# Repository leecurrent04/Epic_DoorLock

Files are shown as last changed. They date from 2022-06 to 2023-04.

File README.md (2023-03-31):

# EPIC Door Lock Project

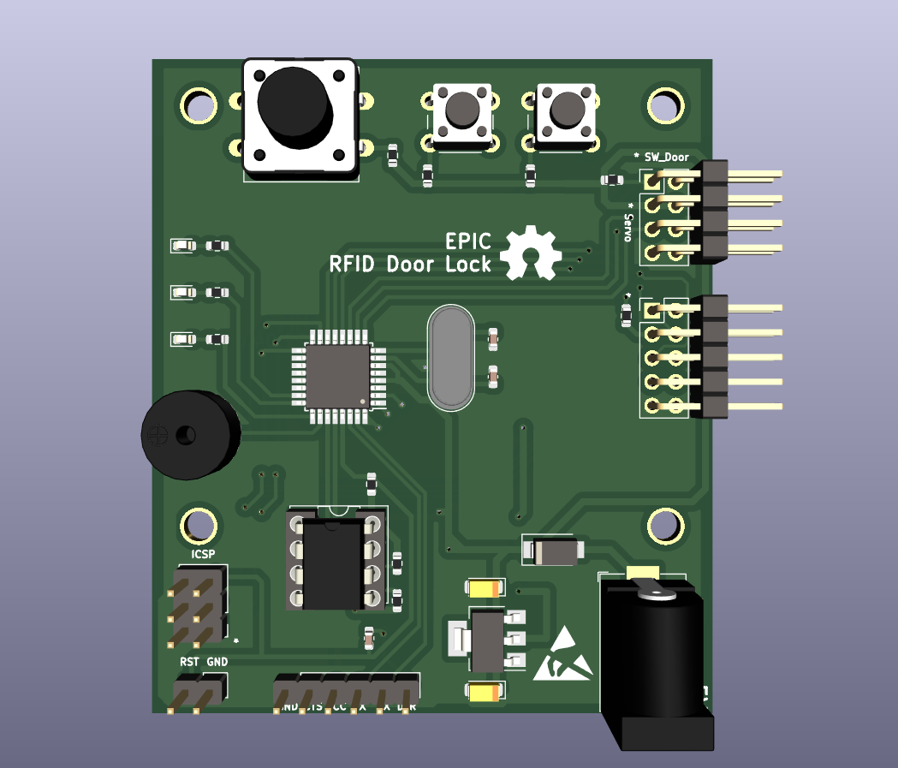
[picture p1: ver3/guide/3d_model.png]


## 1. 프로젝트 소개

연초고등학교 EPIC 동아리(2021~2022) 에서 교내 학생들의 자발적인 탐구 활동을 장려하기 위해 진행한 프로젝트 입니다.<br>
하드웨어 설계는 [KiCAD](https://www.kicad.org/) 를 사용하였고, 소프트웨어는 avr-gcc 컴파일러를 이용한 avr C 언어로 작성되었습니다.

<br>

## 2. 컴파일

Makefile을 이용하여 컴파일하는 경우, Makefile과 같은 위치에 `out` 폴더를 생성해야 합니다.

| 필요한 패키지 | 설명 |
| :---: | :--- |
| avr-gcc | 컴파일러 |
| avr-libc | 라이브러리 |
| avr-size | 메모리 사용량 확인 |
| avrdude | 업로더 |

<br>

### 1. in Linux

1. Set up (Debian)
    <br>
    패키지 설치는 Debian 기준으로 설명하고 있습니다. 자신의 환경에 맞추어 사용하시길 바랍니다.
    <br>

    ```console
    apt update && apt upgrade
    apt install avr-gcc avr-libc avr-size avrdude
    ```
    <br>

2. Download source code
    <br>
    ```console
    git clone https://github.com/leecurrent04/Epic_DoorLock
    cd ./Epic_DoorLock/ver3/code/avr/
    ```
    <br>

3. Set admin card
    <br>
    [main.c](https://github.com/leecurrent04/Epic_DoorLock/blob/main/ver3/code/avr/main.c) 파일의 16, 17줄을 편집하여 관리자 카드를 등록합니다.<br>
    RFID 카드의 4byte UID 코드를 1byte씩 기입합니다. 카드의 UID 코드는 [[NFC Tools - Google Play]](https://play.google.com/store/apps/details?id=com.wakdev.wdnfc&hl=en) 프로그램을 통하여 알 수 있습니다. (프로그램내 시리얼 번호 확인)<br>
    반드시 등록한 관리자 카드의 갯수에 맞게 `cardAdmin_Num` 값을 변경해주어야 합니다.
    <br>
    ```c
    #define cardAdmin_Num 2
    uint8_t cardAdmin_UID[cardAdmin_Num][4] = {
            {0x12, 0x34, 0x56, 0x78},
            {0x0A, 0x0B, 0x0C, 0x0D}
    };
    ```
    <br>

4. Complile
    <br>
    변경 사항을 저장한 후 아래 명령어를 이용하여 코드를 컴파일 합니다.
    <br>
    ```console
    mkdir out
    make all
    ```
    <br>또는 다음과 같은 명령어를 사용할 수 있습니다.<br>

    ```console
	avr-gcc -Wall -mmcu=atmega168p -Os main.c ./lib/* -o ./out/output.o
	avr-objcopy -j .text -j .data -O ihex ./out/output.o ./out/main.hex
    ```
    <br>

5. Upload
    <br>
    [Makefile](https://github.com/leecurrent04/Epic_DoorLock/blob/main/ver3/code/avr/Makefile) 의 2, 4, 5번째 줄을 환경에 맞게 편집합니다.<br>

    ```makefile
    PORT=/dev/ttyUSB0       # SET YOUR PORT
    OBJ_FILES=./lib/*
    BaudRate=115200         # SET BuadRate
    PROGRAMMER=arduino      # SET Programmer
    ```

    <br>아래의 명령어를 터미널에 입력하여 업로드 합니다.<br>

    ```console
    make flash
    ```

    <br>USBtinyISP를 사용하는 경우(권장), 다음의 명령어를 터미널에 입력하면 됩니다.<br>

    ```console
	avrdude -v -p m168p -c usbtiny -U flash:w:./out/main.hex:i
    ```

    <br><br>

### 2. Windows & Mac

[Microchip AVR GCC Compiler](https://www.microchip.com/en-us/tools-resources/develop/microchip-studio/gcc-compilers) 를 사용하여 Linux와 같은 과정을 따르거나, ATMEL Studio를 사용하십시오. <br>
자세한 과정은 『아트멜 스튜디오와 아두이노로 배우는 ATmega328 프로그래밍(허경용)』 도서를 참고하십시오.<br>
(이 프로젝트는 ATmega168p을 사용하였으므로, 업로드 과정에서 유의)
<br><br>

## 4. 참고 라이브러리

RFID 관련 AVR 라이브러리 : https://github.com/asif-mahmud/MIFARE-RFID-with-AVR

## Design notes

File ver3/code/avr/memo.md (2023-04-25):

-----

# library

https://github.com/asif-mahmud/MIFARE-RFID-with-AVR

-----

# Var: doorState

doorState 변수는 문 열림 동작에 관여하는 변수이다. <br> 
다음과 같은 변수를 사용하지 않는다면, 도어락이 정상적으로 작동하지 않을 우려가 있다.<br><br>

### 동작 과정) doorState = 0b00;

|  No | Situation | 0b_0  | 0b0_  | PIND6 |
| :---: | :--- | :---: | :---: | :---: |
| 1 | Normal | 0 | 0 | 0 |
| 2 | BTN Pressed | 1 | 1 | 0 |
| 3 | When Door opened  | 1 | 1 | 1 |
| 4 | After Door opened | 1 | 0 | 1 |
| 5 | Door closed | 1 | 0 | 0 |
| 6 | Normal | 0 | 0 | 0 |

<br>PIND6 는 문열림 감지 스위치이다. 풀 업(PULL UP) 저항으로 동작하지만, 이해를 위해 풀 다운(PULL DOWN)으로 상황으로 작성하였다. 실제 코드에서는 풀업 기준으로 작성되어 있다.<br><br>

# Var: btnPressed

btnPressed 변수는 도어락 버튼 동작에 관여하는 변수이다. <br>
각 버튼의 PIN을 사용하지 않고 btnPressed 변수를 사용함으로써 채터링 현상을 방지할 수 있다.<br>

BTN_D2 : 0b100  : 열기 버튼 <br>
BTN_D3 : 0b010  : 등록 버튼 <br>
BTN_D4 : 0b001  : 삭제 버튼 <br>
<br><br>

### 동작 과정)
|  No | Situation |  var  | BTN_Dn |
| :---: | :--- | :---: | :----: |
| 1 | Normal | 0 | 0 |
| 2 | When BTN Pressed  | 0 | 1 |
| 3 | After BTN Pressed | 1 | 1 |
| 4 | BTN Unpressed | 1 | 0 |
| 5 | Execute Function  | 1 | 0 |
| 6 | Normal | 0 | 0 |

<br>

-----

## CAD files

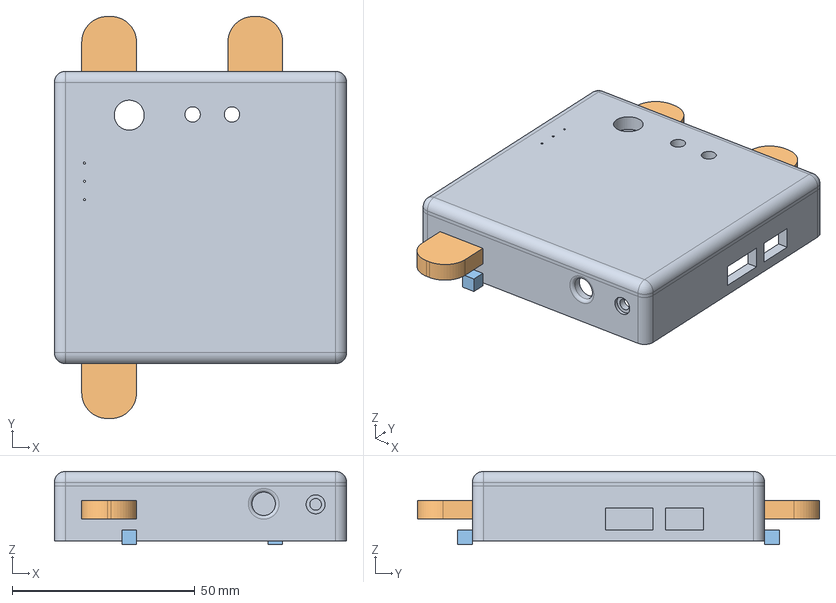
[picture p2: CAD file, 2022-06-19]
ver3/3D/RFID_Case-cover.step
80.0 x 110.0 x 20.0 mm
top
guide_cover
guide_cover001
guide_cover002
lock
lock001
lock002

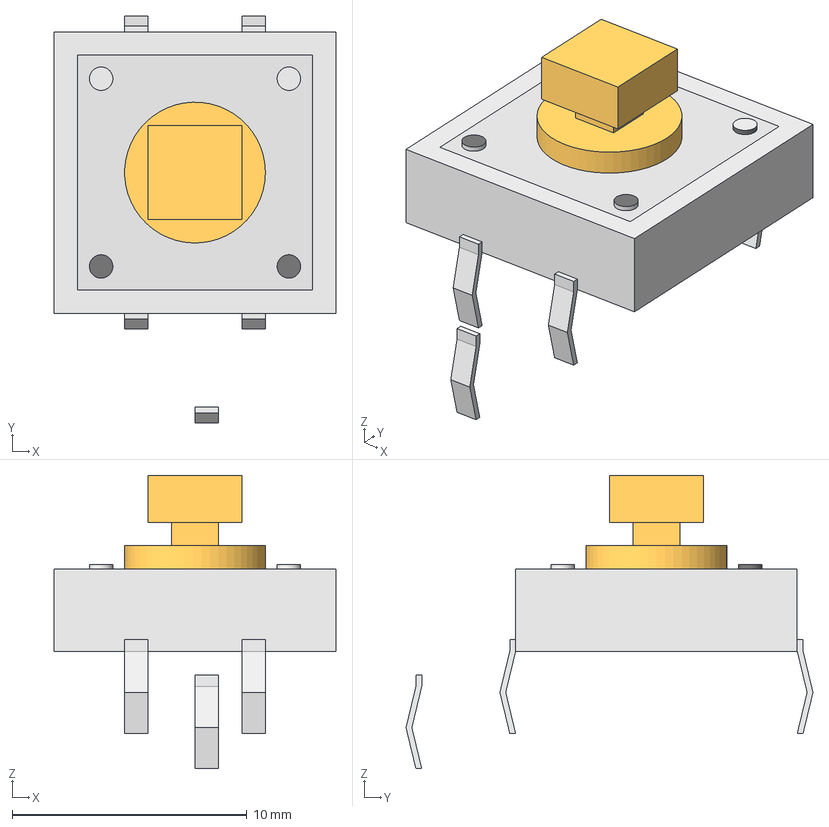
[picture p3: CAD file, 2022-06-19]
ver3/pcb/lib_o/NW3-TS-G008.step
12.0 x 17.3 x 12.5 mm
inner_Body x 2
knob x 2
leg x 2
Sketch
Sketch001
Local_CS
CopyChamfer
Sketch002
Sketch003
Local_CS001
Local_CS002
CopyPad001
Sketch004
BaseFeature
Local_CS003
CopyPocket001
Sketch005
Sketch006
Sketch007
Sketch008
Sketch009
Pad005 (Mirror #1)
leg (Mirror #2)
Pad005 (Mirror #3)

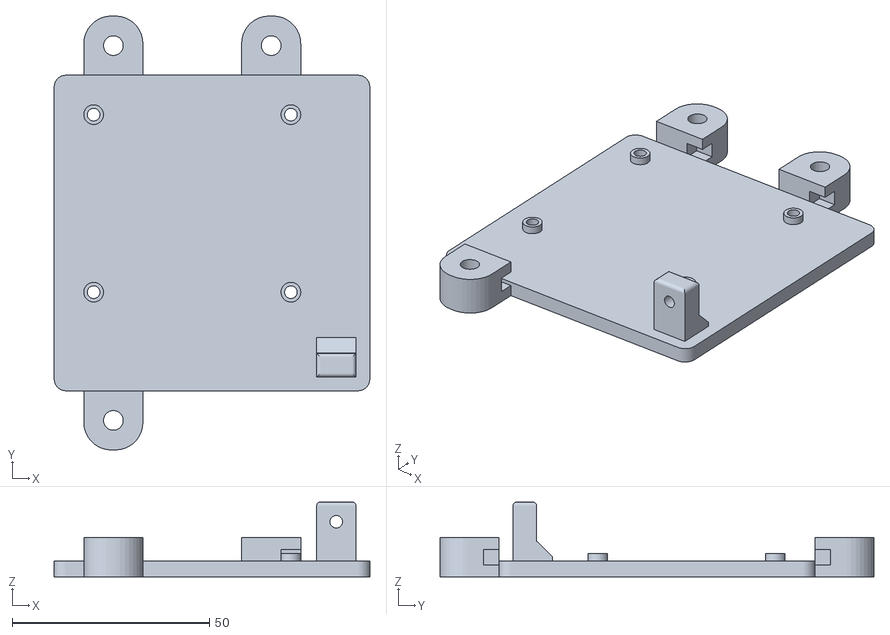
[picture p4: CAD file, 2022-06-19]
ver3/3D/RFID_Case-pcb 1.stl
80.0 x 110.0 x 19.0

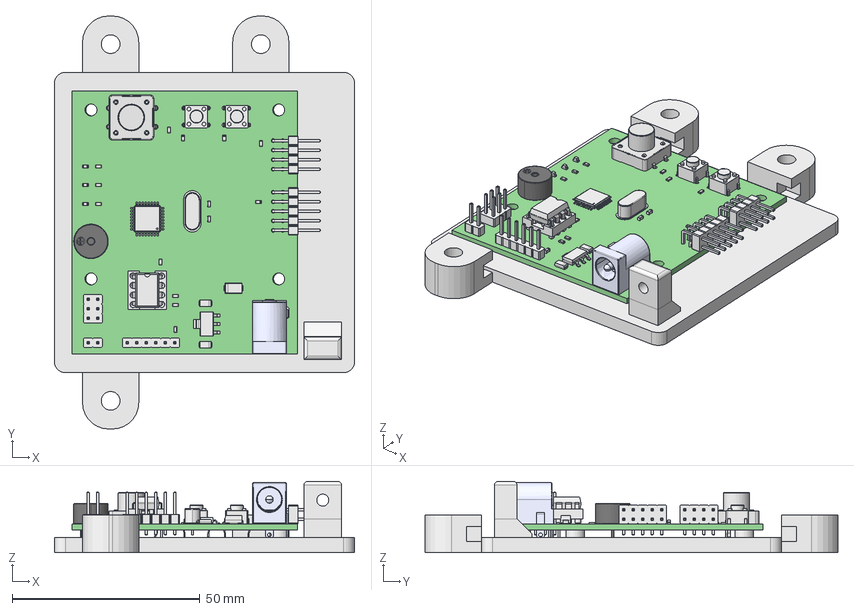
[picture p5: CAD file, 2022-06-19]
ver3/3D/RFID_Case.FCStd
80.0 x 110.0 x 19.0 mm
top001
guide001
guide003
guide002
lock_hole001
pcb PCB

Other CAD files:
ver3/3D/RFID_Case-cover.stl

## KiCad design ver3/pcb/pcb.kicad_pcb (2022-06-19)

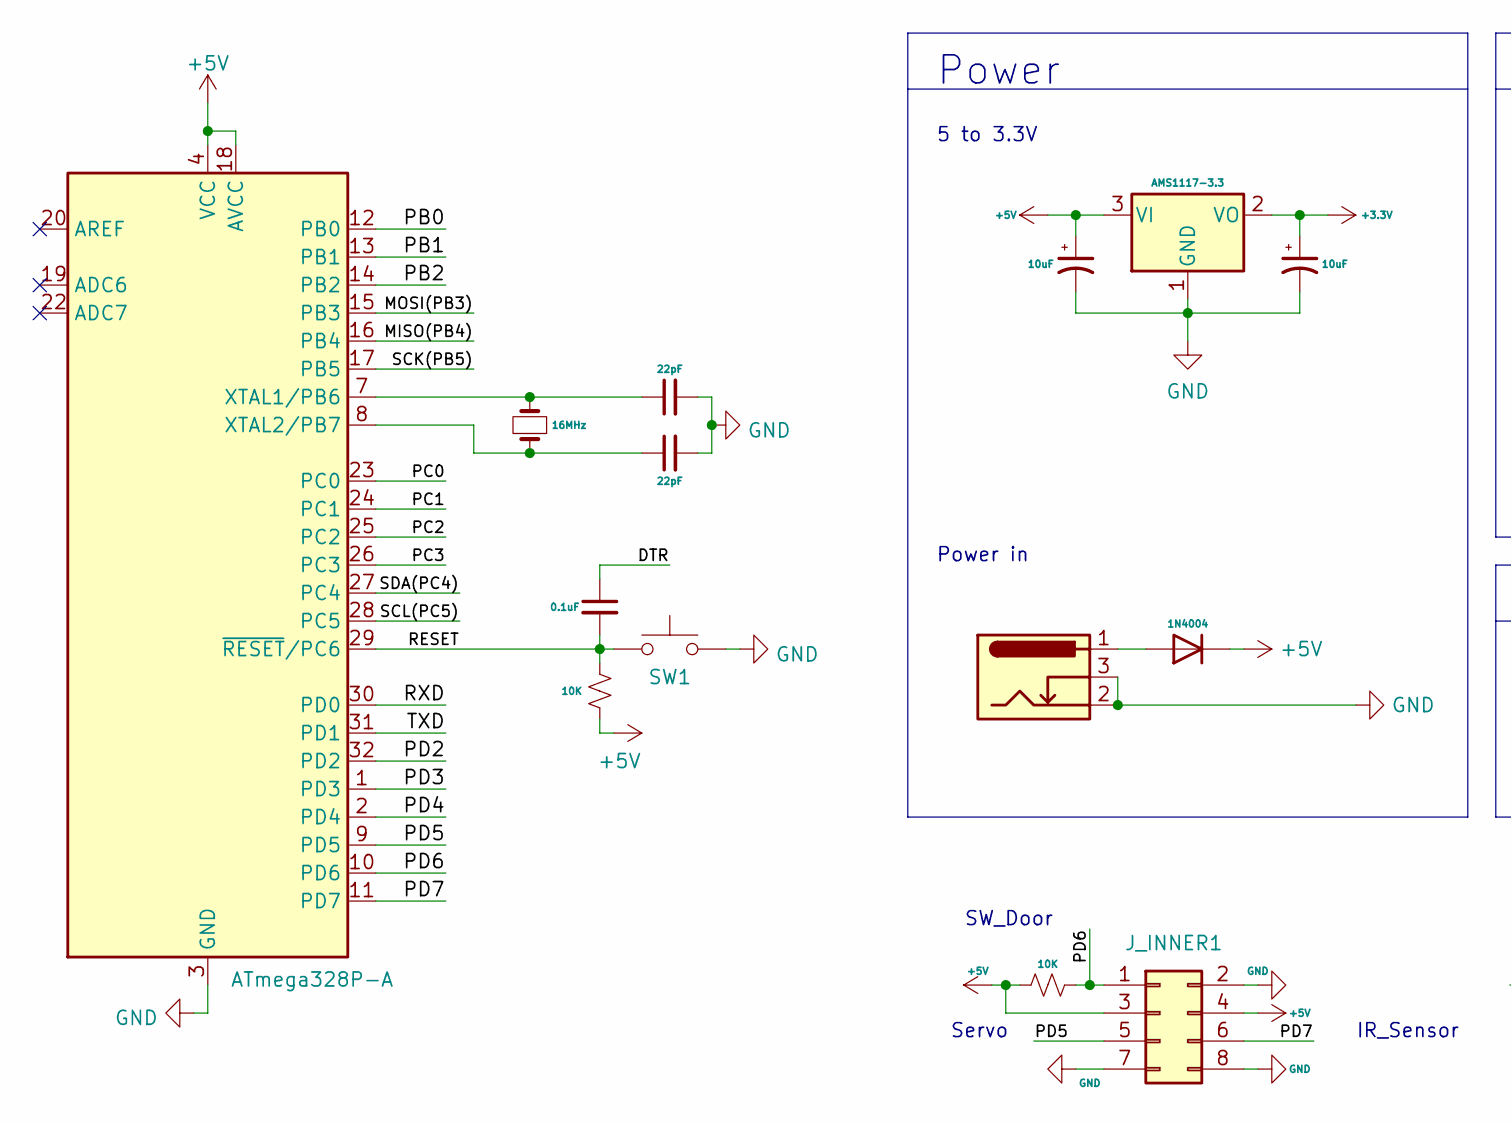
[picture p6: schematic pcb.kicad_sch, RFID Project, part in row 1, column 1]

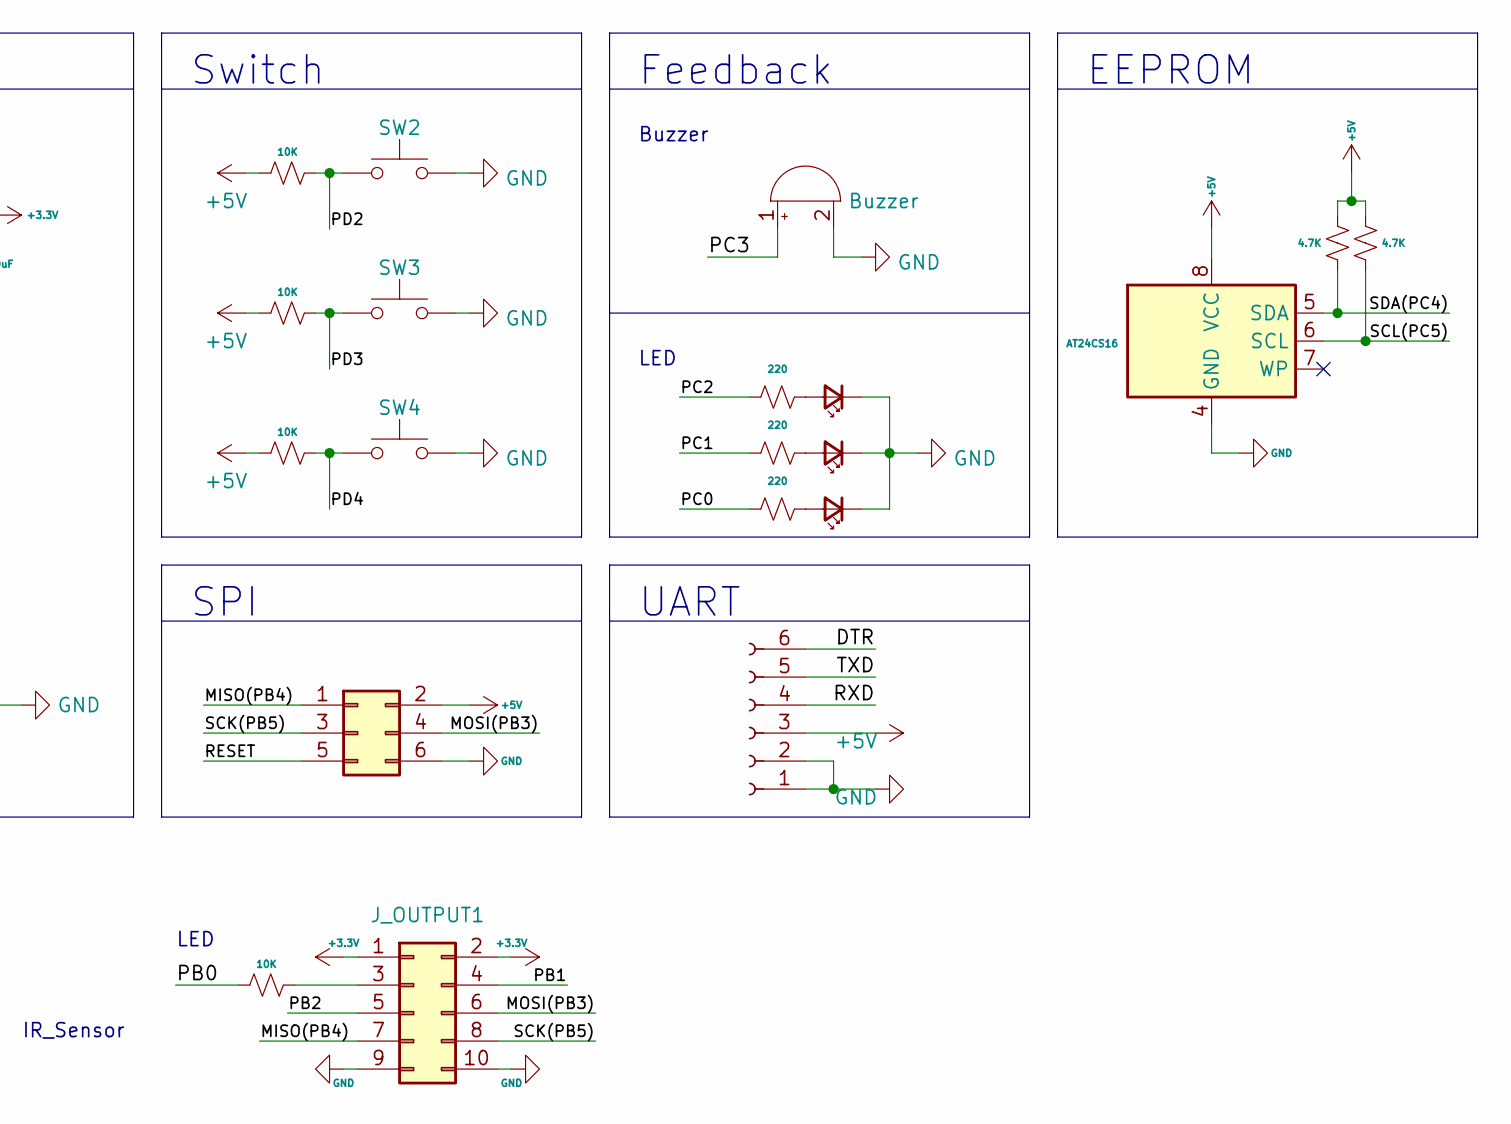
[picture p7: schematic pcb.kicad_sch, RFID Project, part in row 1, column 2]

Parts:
BZ1: Buzzer; FQ-014[Buzzer]
C1: 0.1uF; C_0603_1608Metric
C2, C3: 22pF; C_0603_1608Metric
C4, C5: 10uF; CP_EIA-3216-10_Kemet-I
D1: 1N4004; D_SMA
D2, D3, D4: LED_Small; LED_0603_1608Metric
J_INNER1: Conn_02x04_Odd_Even; PinHeader_2x04_P2.54mm_Vertical
J_OUTPUT1: Conn_02x05_Odd_Even; PinHeader_2x05_P2.54mm_Vertical
J_SPI1: Conn_02x03_Odd_Even; PinHeader_2x03_P2.54mm_Vertical
J_UART1: Conn_01x06_Female; PinHeader_1x06_P2.54mm_Vertical
POWER_JACK1: 5.5pi; BarrelJack_Horizontal
R1, R2, R3, R4, R5, R6: 10K; R_0603_1608Metric
R7, R8, R9: 220; R_0603_1608Metric
R10, R11: 4.7K; R_0603_1608Metric
SW1: SW_Push; PinHeader_1x02_P2.54mm_Vertical
SW2: SW_Push; SW_PUSH-12mm
SW3, SW4: SW_Push; SW_PUSH_6mm_H5mm
U1: ATmega328P-A; TQFP-32_7x7mm_P0.8mm
U2: AMS1117-3.3; SOT-223-3_TabPin2
U3: AT24CS16; DIP-8_W7.62mm_Socket_LongPads
Y1: 16MHz; Crystal_HC49-4H_Vertical

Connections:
+3V3: C5.1, J_OUTPUT1.1, J_OUTPUT1.2, U2.2 (VO)
+5V: C4.1, D1.1 (K), J_INNER1.3, J_INNER1.4, J_SPI1.2, J_UART1.3, R1.1, R2.2, R4.1, R5.1, R6.1, R10.1, R11.1, U1.4 (VCC), U1.6 (VCC), U1.18 (AVCC), U2.3 (VI), U3.8 (VCC)
/DTR: C1.1, J_UART1.6
/MISO(PB4): J_OUTPUT1.7, J_SPI1.1, U1.16 (PB4)
/MOSI(PB3): J_OUTPUT1.6, J_SPI1.4, U1.15 (PB3)
/PB0: R3.1, U1.12 (PB0)
/PB1: J_OUTPUT1.4, U1.13 (PB1)
/PB2: J_OUTPUT1.5, U1.14 (PB2)
/PC0: R9.1, U1.23 (PC0)
/PC1: R8.1, U1.24 (PC1)
/PC2: R7.1, U1.25 (PC2)
/PC3: BZ1.1 (-), U1.26 (PC3)
/PD2: R4.2, SW2.1, U1.32 (PD2)
/PD3: R5.2, SW3.1, U1.1 (PD3)
/PD4: R6.2, SW4.1, U1.2 (PD4)
/PD5: J_INNER1.5, U1.9 (PD5)
/PD6: J_INNER1.1, R2.1, U1.10 (PD6)
/PD7: J_INNER1.6, U1.11 (PD7)
/RESET: C1.2, J_SPI1.5, R1.2, SW1.1, U1.29 (~RESET/PC6)
/RXD: J_UART1.4, U1.30 (PD0)
/SCK(PB5): J_OUTPUT1.8, J_SPI1.3, U1.17 (PB5)
/SCL(PC5): R11.2, U1.28 (PC5), U3.6 (SCL)
/SDA(PC4): R10.2, U1.27 (PC4), U3.5 (SDA)
/TXD: J_UART1.5, U1.31 (PD1)
GND: BZ1.2 (+), C2.2, C3.2, C4.2, C5.2, D2.1 (K), D3.1 (K), D4.1 (K), J_INNER1.2, J_INNER1.7, J_INNER1.8, J_OUTPUT1.9, J_OUTPUT1.10, J_SPI1.6, J_UART1.1, J_UART1.2, POWER_JACK1.2, POWER_JACK1.3, SW1.2, SW2.2, SW3.2, SW4.2, U1.3 (GND), U1.5 (GND), U1.21 (GND), U2.1 (GND), U3.4 (GND)
unnamed: C2.1, U1.7 (XTAL1/PB6), Y1.2
unnamed: C3.1, U1.8 (XTAL2/PB7), Y1.1
unnamed: D1.2 (A), POWER_JACK1.1
unnamed: D2.2 (A), R7.2
unnamed: D3.2 (A), R8.2
unnamed: D4.2 (A), R9.2
unnamed: J_OUTPUT1.3, R3.2

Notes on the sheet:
Feedback
Power in
Power
Servo
UART
Buzzer
IR_Sensor
LED
SW_Door
SPI
5 to 3.3V
EEPROM
Switch

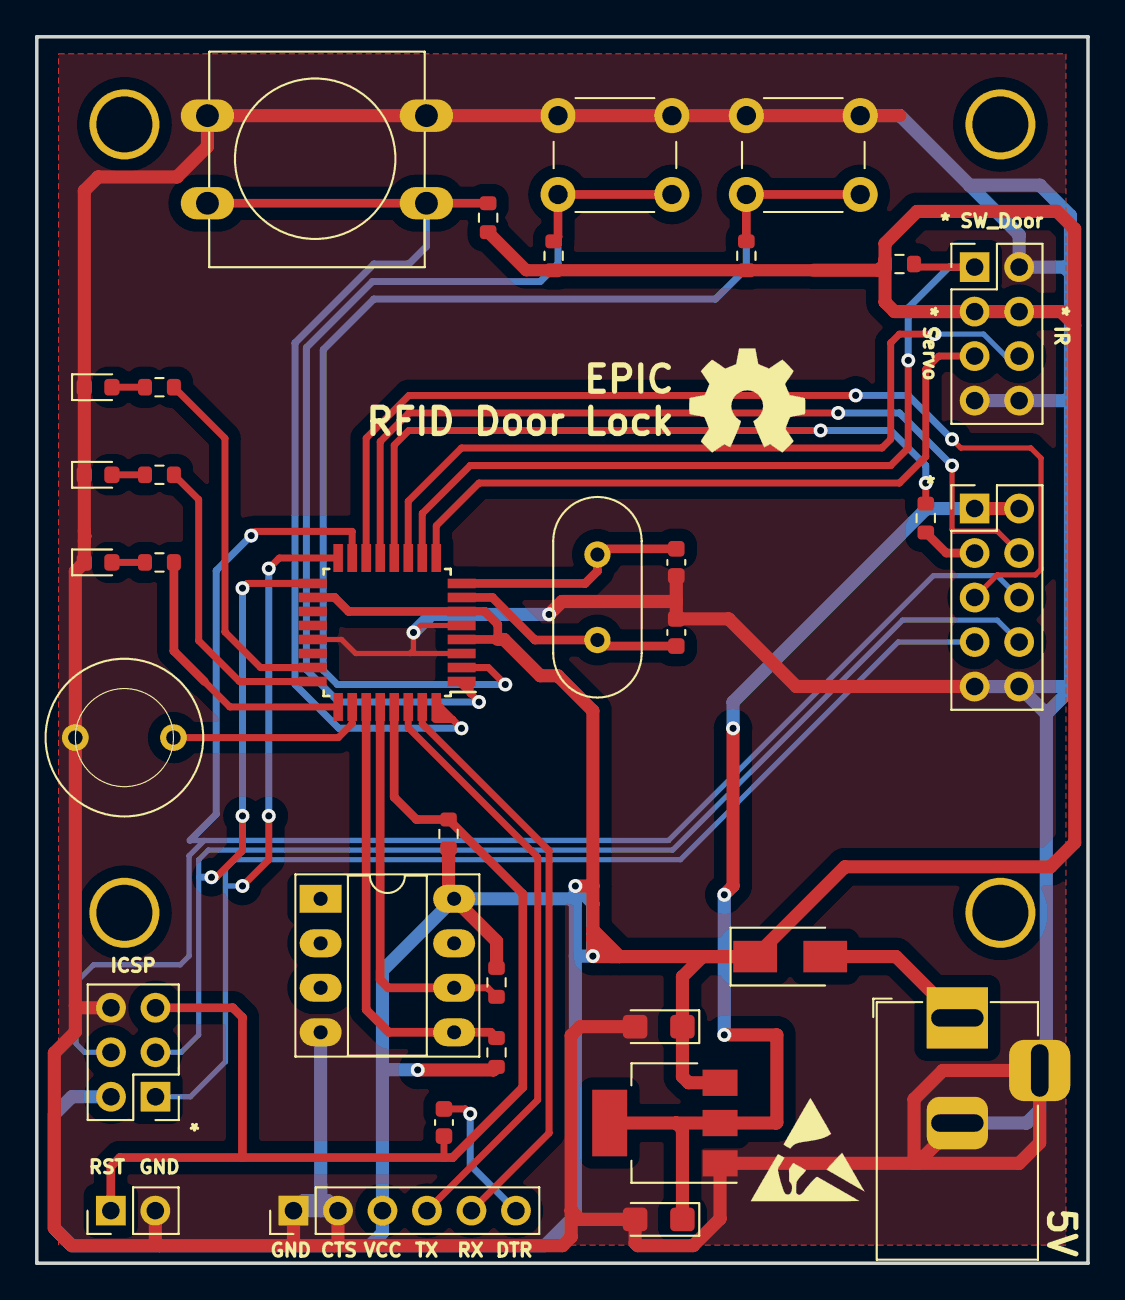
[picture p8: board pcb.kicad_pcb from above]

Board: 2 copper layers, 60.0 x 70.0 mm, 40 parts (0 on the bottom side), 32 nets.

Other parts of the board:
HOLE1, HOLE2, HOLE3, HOLE4: (no value)
REF_ESD: ESD-Logo_6.6x6mm_SilkScreen
REF_OSHW: OSHW-Symbol_6.7x6mm_SilkScreen

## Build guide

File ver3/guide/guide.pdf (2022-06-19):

### RFID 도어락 간단 사용 설명서

2022.04.06

### 1. 부품 식별

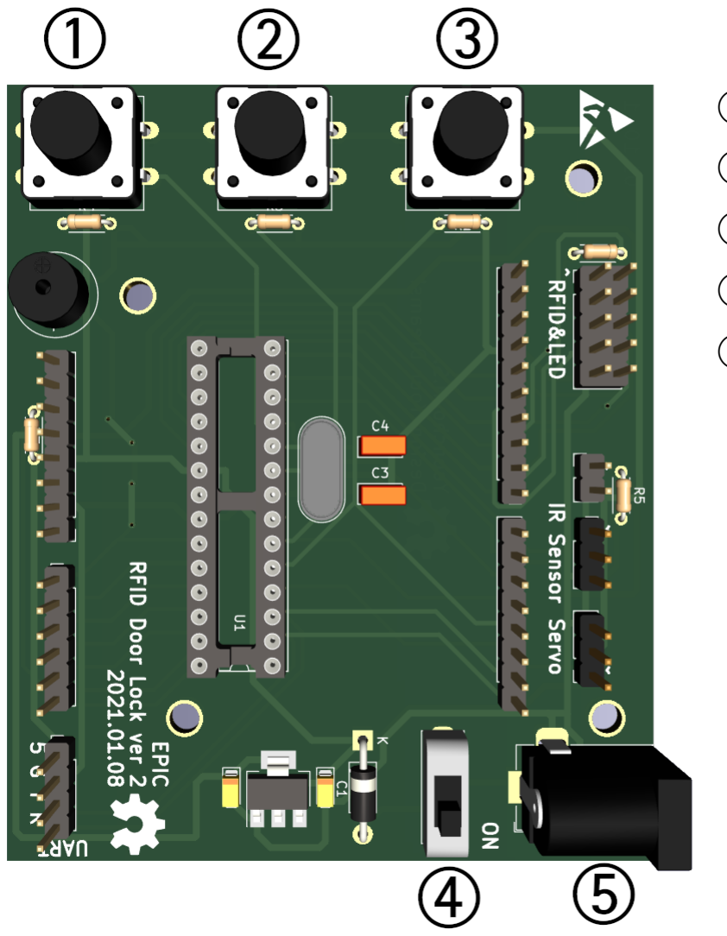
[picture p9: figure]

### ① : [초기화] 버튼

### ② : [문 열림] 버튼

### ③ : [등록] 버튼

### ④ : 전원 스위치

### ⑤ : 전원 잭

문 열기

1. [문 열림] 버튼 누르기

카드 등록

사용할 카드를 등록합니다. Mifare Classic 1K(13.56MHz) 카드 사용을 권장합니다.

모든 과정은 비프가 끝난 후 수행해야 합니다.

1. [등록] 버튼 누르기
2. 비프(1초) 후, 관리자 카드 태그
3. 비프(3초) 후, 등록할 카드 태그
4. 비프(1초) 후, 완료

카드 초기화
등록한 모든 카드를 삭제합니다. 관리자 카드는 삭제되지 않습니다.
1. [초기화] 버튼 누르기
2. 비프(1초) 후, 관리자 카드 태그
3. 비프(1초) 후, 완료

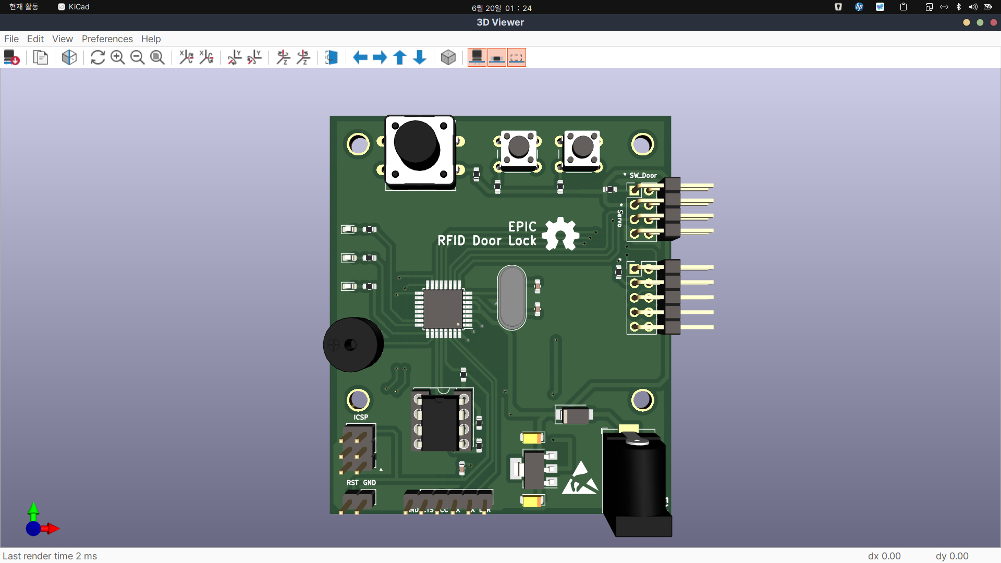
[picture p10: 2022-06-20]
ver3/guide/3d_img.png

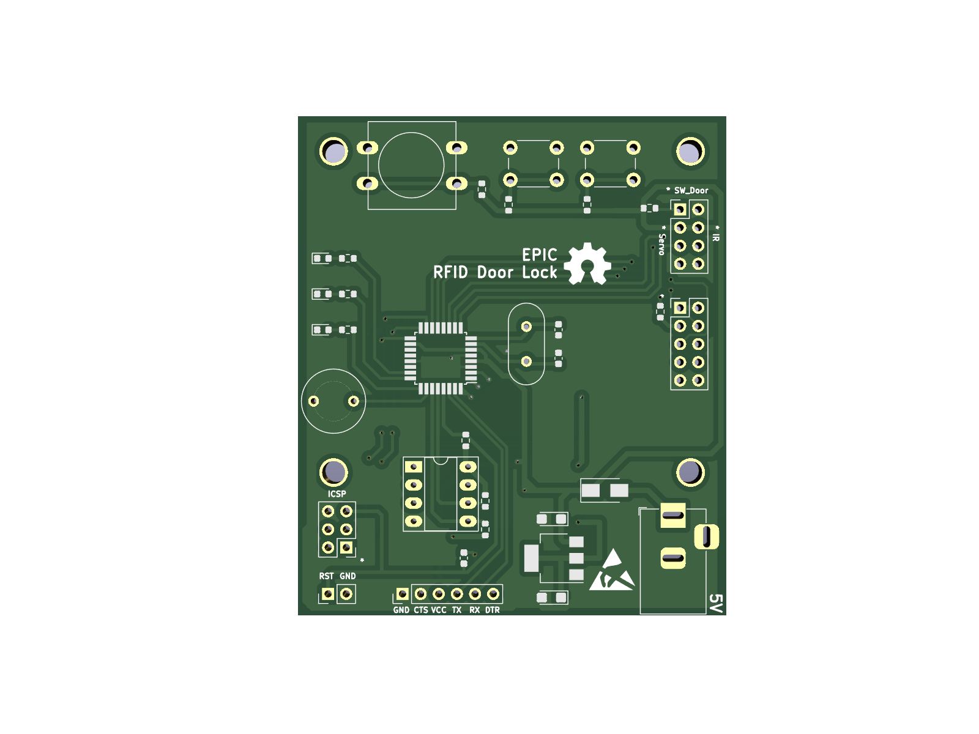
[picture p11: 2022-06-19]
ver3/guide/pcb.png

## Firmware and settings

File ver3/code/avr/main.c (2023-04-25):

#define F_CPU 16000000L
#include <avr/io.h>
#include <util/delay.h>
#include <avr/wdt.h>
#include "./include/PCB_pin.h"

// RFID MFRC522
#include "./include/spi.h"
#include "./include/mfrc522.h"

// 관리자 key의 개수. 주의 요망!
#define cardAdmin_Num 1
uint8_t cardAdmin_UID[cardAdmin_Num][4] = {
        {0x00, 0x00, 0x00, 0x00}
};


int main(void){
    board_setup();

    while(1){
        // RFID 인식 안되면 리셋
        byte = mfrc522_read(VersionReg);
        if(byte != 0x92) {
            wdt_reset();
        }

        //==============================
        // 문 열기 버튼이 눌렸을 때
        if( (PIND&BTN_D2)!=BTN_D2 ){
            // 버튼이 처음 눌리면)
            if(!( (btnPressed&0b100) >>2) ) {
                btnPressed |= 0b100;    // 버튼 상태 변수를 변경

                // 문열기
                if( (PIND&D_BTN_D6)!=D_BTN_D6 && doorState == 0b00 ){
                    doorState = 0b11;
                    doorOpen();
                }
            }
        }
        else{
            // 버튼에서 손을 때면
            if((btnPressed&0b100)>>2){
                btnPressed&=0b011;      // 초기 상태로 변경
                _delay_ms(BtnDTime);
            }
        }

        //==============================
        // 등록 버튼이 눌렸을 때
        if( (PIND&BTN_D3)!=BTN_D3 ) {
            if(!((btnPressed&0b010)>>1)) {
                btnPressed |= 0b010;
            }
        }
        else{
            if((btnPressed&0b010)>>1) {
                btnPressed&=0b101;
                _delay_ms(BtnDTime);
                PORTC |= LED_C1;

                uint8_t exitState = 0;
                // 관리자 권한 카드 인식 될 때까지 대기
                while (0 != checkRFID(1,card_Num)) {
                    // 카드 최대 개수(2Kbyte, addr: 0~2048)
                    // 2048÷4-1=511
                    if(card_Num>=511){
                        PORTC |= BUZZ_C3|LED_C0|LED_C1;
                        _delay_ms(BuzzerTime);
                        PORTC &= ~(BUZZ_C3|LED_C0|LED_C1);

                        exitState =1;
                        break;
                    }

                    // 버튼 누르면 나가기
                    if ((PIND & BTN_D3) != BTN_D3) {
                        // 만약 버튼을 처음 누른다면
                        if (!((btnPressed & 0b010) >> 1)) {
                            btnPressed |= 0b010;

                            // Buzzer
                            beep_buzzer();
                            PORTC &= ~LED_C1;

                            exitState = 1;
                        }
                    }
                    else {
                        // 버튼이 이미 눌려져 있었다면
                        if ((btnPressed & 0b010) >> 1) {
                            btnPressed &= 0b101;
                            _delay_ms(BuzzerTime);
                            break;
                        }
                    }
                }
                if (exitState){
                    continue;     // 나가기
                }

                // Buzzer
                beep_buzzer();

                uint16_t aUID[4] = {0,};      // UID 값을 읽기 위한 메모리
                uint8_t breakState;           // 이중 반복문을 나가기 위한 변수

                // 카드 등록할 때까지 대기
                while (1) {
                    breakState = 1;

                    // 빈 카드가 아니라면
                    if (0 == readRFID(&aUID[0], &aUID[1], &aUID[2], &aUID[3])) {
                        // 관리자 카드가 아니면 break
                        for (int i = 0; i < cardAdmin_Num; i++) {
                            if ((cardAdmin_UID[i][0] == aUID[0]) && (cardAdmin_UID[i][1] == aUID[1])
                                && (cardAdmin_UID[i][2] == aUID[2]) && (cardAdmin_UID[i][3] == aUID[3])) {
                                breakState = 0;
                                break;
                            }

                        }
                        // 기존에 등록된 카드가 아니면 break
                        for (uint16_t i = 0; i < card_Num; i++) {
                            if ((AT24C_read_byte(4*(i+1)) == aUID[0]) && (AT24C_read_byte(4*(i+1)+1) == aUID[1])
                                && (AT24C_read_byte(4*(i+1)+2) == aUID[2])&& (AT24C_read_byte(4*(i+1)+3) == aUID[3])) {
                                breakState = 0;
                                break;
                            }

                        }
                        if (breakState){
                            break;
                        }
                    }
                }

                //카드 값을 저장
                for (int i = 0; i < 4; i++) {
                    AT24C_write_byte(4*(card_Num+1)+i,aUID[i]);
                    _delay_ms(10);
                }
                // 등록된 카드 수를 늘리고 저장
                card_Num++;
                AT24C_write_byte(0,card_Num>>8);
                _delay_ms(10);
                AT24C_write_byte(1,card_Num&0xFF);
                _delay_ms(10);

                // Buzzer
                beep_buzzer();
                PORTC &= ~LED_C1;
            }
        }

        //==============================
        // 삭제 버튼
        if( (PIND&BTN_D4)!=BTN_D4 ){
            if(!(btnPressed&0b001))
                btnPressed|=0b001;
        }
        else{
            if(btnPressed&0b001){
                btnPressed&=0b110;
                _delay_ms(BtnDTime);
                PORTC |= LED_C2;

                uint8_t exitState = 0;
                // 관리자 카드 대기
                while(0!=checkRFID(1,card_Num)){
                    if((PIND&BTN_D4)!=BTN_D4){
                        btnPressed|=0b001;

                        // Buzzer
                        beep_buzzer();
                        PORTC &= ~LED_C2;

                        exitState = 1;
                    }
                    else{
                        if(btnPressed&0b001){
                            btnPressed&=0b110;
                            _delay_ms(BtnDTime);
                            break;
                        }
                    }
                }
                if(exitState) {
                    continue;
                }

                // 카드 갯수 초기화
                card_Num = 0;
                AT24C_write_byte(0,card_Num>>8);
                _delay_ms(10);
                AT24C_write_byte(1,card_Num&0xFF);
                _delay_ms(10);

                // Buzzer
                beep_buzzer();
                PORTC &= ~LED_C2;
            }
        }

        //==============================
        // 도어 스위치가 눌렸다면
        if( (PIND&D_BTN_D6)!=D_BTN_D6 ) {
            // 만약 문이 닫인 상황에서 카드가 인증되면
            if (!checkRFID(0,card_Num)) {
                // 문이 닫혀 있었다면 문 열기
                if (doorState == 0b00) {
                    doorState = 0b11;
                    doorOpen();
                }
            }

            // 만약 문을 닫았다면
            if(doorState==0b10) {
                doorState = 0b00;   // 초기 상태
                doorClose();        // 문 닫기
            }
        }
            // 만약 문을 열었다면
        else {
            // 문열림 버튼 상태를 변경
            if(doorState==0b11)
                doorState=0b10;
        }
    }
    return 0;
}


void board_setup(void){
    DDRC = 0x0F;          // LED, Buzzer
    DDRD = 0x20;          // Servo

    PORTC |= BUZZ_C3;     // 점검용 부저 켜기

    // UART_INIT();     // UART
    doorState = 0b00;     // 문 동작 관련 상태 변수. memo.md 파일 참고
    btnPressed = 0b000;   // 버튼 눌림 관련 상태 변수. memo.md 파일 참고

    // 문 닫기
    doorClose();

    spi_init();         // SPI 작동
    _delay_ms(50);

    mfrc522_init();     // rfid 리더기 연결

    // RFID 작동 안하면 리셋
    byte = mfrc522_read(VersionReg);
    if(byte != 0x92) {
        wdt_reset();
    }

    byte = mfrc522_read(ComIEnReg);
    mfrc522_write(ComIEnReg,byte|0x20);
    byte = mfrc522_read(DivIEnReg);
    mfrc522_write(DivIEnReg,byte|0x80);

    // I2C 작동(EEPROM)
    TWCR = (1<<TWEN);
    TWBR = 12;          //400khz

    // EEPROM 0,1번에서 1byte 씩 가져와 2byte 값으로
    card_Num = AT24C_read_byte(0)<<8|AT24C_read_byte(1);

    PORTC &= ~BUZZ_C3;  // 점검용 부저 끄기
    return;
}

void beep_buzzer(void){
    PORTC |= BUZZ_C3;
    _delay_ms(BuzzerTime);
    PORTC &= ~BUZZ_C3;
    return;
}


/*
 *  카드를 확인하는 함수
 *  boolAdmin) 1: Admin only, 0: All
 *  return) 1: Error, 0: Pass
 */
uint8_t checkRFID(uint8_t boolAdmin,uint16_t card_Num){
    byte = mfrc522_request(PICC_REQALL,str);

    if(byte == CARD_FOUND){
        byte = mfrc522_get_card_serial(str);
        if(byte == CARD_FOUND){
            // 관리자 카드 검사
            for(uint8_t n=0; n<cardAdmin_Num;n++){
                if( (str[0]==cardAdmin_UID[n][0]) && (str[1]==cardAdmin_UID[n][1]) &&
                    (str[2]==cardAdmin_UID[n][2]) && (str[3]==cardAdmin_UID[n][3]) ){
                    return 0;
                }
            }

            // 일반 사용자 카드도 검사
            if( !boolAdmin ){
                for(uint16_t n=0; n<card_Num;n++){
                    if( (str[0]== AT24C_read_byte(4*(n+1))) && (str[1]== AT24C_read_byte(4*(n+1)+1)) &&
                        (str[2]==AT24C_read_byte(4*(n+1)+2)) && (str[3]==AT24C_read_byte(4*(n+1)+3)) ){
                        return 0;
                    }
                }
            }
        }
    }
    return 1;
}

// RFID UID 값을 읽어오는 함수 (return 1: error)
// 포인터 주소 필요함.
uint8_t readRFID(uint16_t *tempUID0, uint16_t *tempUID1, uint16_t *tempUID2, uint16_t *tempUID3) {
    byte = mfrc522_request(PICC_REQALL, str);
    if (byte == CARD_FOUND) {

        byte = mfrc522_get_card_serial(str);
        if (byte == CARD_FOUND) {
            // 포인터에 카드 값을 입력
            *tempUID0 = str[0];
            *tempUID1 = str[1];
            *tempUID2 = str[2];
            *tempUID3 = str[3];

            return 0;
        }
    }
    return 1;
}

void doorOpen() {
    for (int i = 0; i < Servo_PulseNum; i++) {
        PORTD |= ServoPin;
        _delay_ms(2.5);
        PORTD &= ~ServoPin;
        _delay_ms(17.5);
    }

    // Buzzer
    beep_buzzer();
    return;
}

void doorClose(void){
    // 문 닫기
    for(int i=0;i<Servo_PulseNum;i++){
        PORTD |= ServoPin;
        _delay_ms(1.5);
        PORTD &= ~ServoPin;
        _delay_ms(18.5);
    }

    // Buzzer
    beep_buzzer();
    return;
}

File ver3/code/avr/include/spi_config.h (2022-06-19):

/*
 * spi_config.h
 * 
 * Copyright 2013 Shimon <shimon@monistit.com>
 * 
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
 * 
 */
#ifndef SPI_CONFIG_H
#define SPI_CONFIG_H

#include <avr/io.h>

/*
 * Set to 1, spi api will work in master mode
 * else in slave mode
 */
#define SPI_CONFIG_AS_MASTER 	1


/*
 * Config SPI pin diagram
 */
#define SPI_DDR		DDRB
#define SPI_PORT	PORTB
#define SPI_PIN		PINB

//#define SPI_MOSI	0x03
//#define SPI_MISO	0x04
//#define SPI_SS		0x02
//#define SPI_SCK		0x05

#define SPI_MOSI	PB3
#define SPI_MISO	PB4
#define SPI_SS		PB2
#define SPI_SCK		PB5

#endif

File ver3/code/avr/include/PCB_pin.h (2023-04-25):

//
// Created by leecurrent04 on 22. 5. 13.
//

#ifndef AVR_PCB_PIN_H
#define AVR_PCB_PIN_H

#include "mfrc522.h"

#define LED_C0 0x01     // PC0
#define LED_C1 0x02     // PC1
#define LED_C2 0x04     // PC2
#define BUZZ_C3 0x08    // PC3
#define BTN_D2 0x04     // PD2
#define BTN_D3 0x08     // PD3
#define BTN_D4 0x10     // PD4
#define D_BTN_D6 0x40   // PD6
#define ServoPin 0x20   // PD5

#define BuzzerTime 500
#define BtnDTime 100

#define Servo_PulseNum 20

uint16_t card_Num;

uint8_t doorState;
uint8_t btnPressed;     // 버튼의 눌림 기록

// mfc522
uint8_t byte;
uint8_t str[MAX_LEN];

//Function
uint8_t checkRFID(uint8_t,uint16_t card_Num);
uint8_t readRFID(uint16_t *, uint16_t *, uint16_t *, uint16_t *);

void board_setup(void);
void beep_buzzer(void);
void doorOpen(void);
void doorClose(void);

unsigned char AT24C_write_byte(unsigned int,unsigned char);
unsigned char AT24C_read_byte(unsigned int addr);

#endif //AVR_PCB_PIN_H

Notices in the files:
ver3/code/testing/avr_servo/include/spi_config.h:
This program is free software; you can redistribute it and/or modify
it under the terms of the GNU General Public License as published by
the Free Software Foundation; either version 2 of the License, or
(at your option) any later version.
